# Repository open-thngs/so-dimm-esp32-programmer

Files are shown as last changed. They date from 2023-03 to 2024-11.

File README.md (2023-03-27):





---

# KiCAD-CICD-Template

This repository provides different CI/CD workflows used for projects using [KiCAD](https://www.kicad.org/) and [PlatformIO](https://platformio.org).

## workflows

### KiBot

[KiBot](https://github.com/INTI-CMNB/KiBot/) is used to generate all kind of documentation from a KiCAD6 project.

Whenever a file matching `pcb/*.kicad_*` changes this workflow will trigger.

The following documents are generated on every build:

```
- pcb/cad/
   - dxf/
      - AutoCAD - DXF
   - boardview - BRD
   - 3D render - STEP
- pcb/docs/
   - bom/
      - Interactive BOM - HTML
      - Octopart list - CSV
      - KiCost - XLSX (disabled)
   - schematic - PDF
- pcb/img/
   - pcb/$fab/$style/
      - PCB top - SVG
      - PCB bottom - SVG
   - render/ (disabled)
      - PCB render - PNG
   - schematic - SVG
- pcb/gerbers - ZIP
```

### PlatformIO

used to rebuild your source code whenever it changes.

### REUSE

used to insure every file got a propper license. 

## getting started

- [ ] hit the "use this template" button and give your project a name
- [ ] clone this new repository localy
- [ ] replace content of README.md
- [ ] Code
   - [ ] put your code in the `src/` folder using platformio
- [ ] PCB
   - [ ] change the filenames in `pcb/*.kicad_*` matching your repository name
   - [ ] create your PCB
- [ ] run `reuse --lint`
   - [ ] make sure the licenses of `pcb/*` fits your needs
   - [ ] make sure the licenses of `src/*`, `include/*`, `lib/*`, `test/*` fits your needs
- [ ] commit and push all those changes regulary to your project

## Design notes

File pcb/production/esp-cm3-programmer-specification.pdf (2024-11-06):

PCB Specifications ESP-CM3-Programmer

PCB Thickness: | 1.03mm
PCB Layer count: | 2
PCB Surface Finish: | HASL
PCB Color: | Green T/B
PCB Silkscreen: | White T/B
PCB Physical Stackup:
Layer | Type | Thickness
F.Cu | Copper | 0.035mm
Dielectric 2 | Core | 1.51mm
B.Cu | Copper | 0.035mm

Dimensions

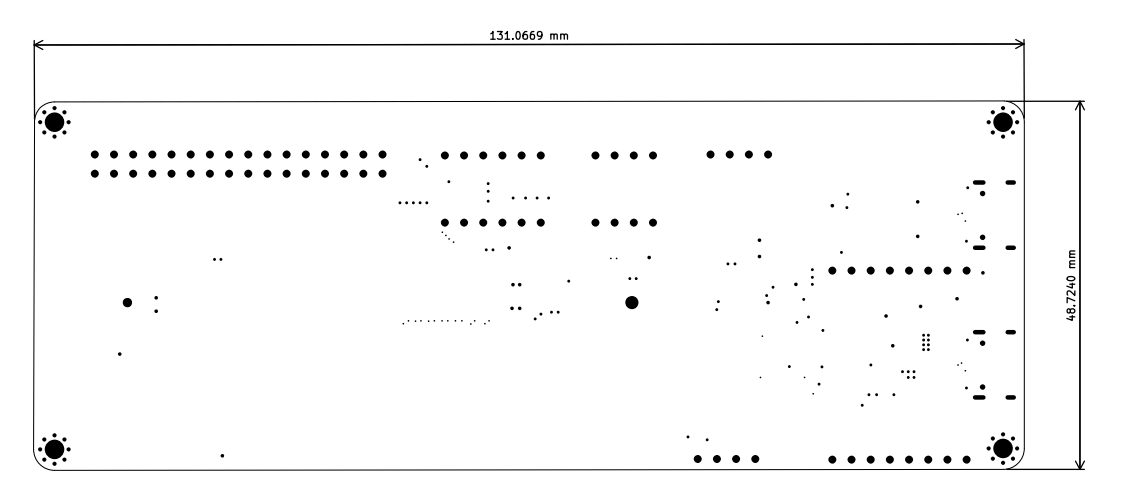
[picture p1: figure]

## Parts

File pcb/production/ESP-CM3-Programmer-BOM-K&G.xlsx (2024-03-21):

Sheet: BIL OF MATERIALS
 |  |  | Kunde: | Mirko Häberlin - open-things
 |  |  | Projektname: | Openthing 1 - ESP-CM3
 |  |  | Menge: | 20, 100
 | KRÜGER & GOTHE GMBH
 | electronic products and services
 | Atzendorfer Str. 19 • 39418 Staßfurt
 | www.kug-ems.de
Pos. | CPN interne Kundenartikelnummer costumer part number | Beschreibung Artikelparameter describtion | Referenzen credentials | T/B | Menge Quantity | MPN Herstellerteilenummer manufacturer part number | Hersteller Manufacturer | MPN Alternative 1 | Hersteller Alternative 1 | MPN Alternative 2 | Hersteller Alternative 2 | Bemerkung
0001 |  | Capacitor 1µF 0603 | C1, C2, C7, C8 | T | 4 | 1uF
0002 |  | Capacitor 0.1µF 0603 | C3, C4, C6 | T | 3 | 0.1uF
0003 |  | Capacitor 10µF 0603 | C5 | T | 1 | 10uF
0004 |  | LED Rot 0603 | D1 | T | 1 | LED RED
0005 |  | 603 | D2 | T | 1 | LED GREEN TX
0006 |  | 603 | D3 | T | 1 | LED GREEN RX
0007 |  | SCHOTTKY Diode SOD-123 | D4, D5 | T | 2 | 1N5819HW-7-F
0008 |  | DDR2-SO-DIMM-Sockel | J1 | T | 1 | 1612618-4 | TE Connectivity
0009 |  | PinHeader_1x06_P2.54mm_Vertical | J12, J2 | T | 2 | Conn_01x06_Pin
0010 |  | PinHeader_1x04_P2.54mm_Vertical | J3, J4, J9 | T | 3 | Conn_01x04_Pin
0011 |  | GCT_USB4105-GF-A | J6, J7 | T | 2 | USB4105-GF-A | Global Connector Technology (GCT) | TYPE-C-31-M-12 | Korean Hroparts Elec
0012 |  | PinHeader_2x16_P2.54mm_Vertical | J8 | T | 1 | Conn_02x16_Odd_Even
0013 |  | NPN+NPN-Digitaltransistor SOT-363_SC-70-6 | Q1 | T | 1 | UMH3N | ROHM Semiconductor
0014 |  | Widerstand 1k 0603 | R1, R10, R11, R12 | T | 4 | 1k
0015 |  | Widerstand 0R 0603 | R13, R14 | T | 2 | 0R
0016 |  | Widerstand 5.1k 0603 | R2, R4, R5, R7 | T | 4 | 5k1
0017 |  | Widerstand 10k 0603 | R3, R6 | T | 2 | 10k
0018 |  | Widerstand 22.1k 0603 | R8 | T | 1 | 22.1k
0019 |  | Widerstand 47.5k 0603 | R9 | T | 1 | 47.5k
0020 |  | Sensorschalter 3.9x2.9x2.0mm 160gf SKRKAEE020 | SW1, SW2 | T | 2 | SKRKAEE020 | Alps Alpine
0021 |  | LDO Spannungs-Regulator 600mA CMOS LDO 50mA 3.3V 250mV SOT-23-5 | U1 | T | 1 | AP2112K-3.3 | Diodes Incorporated
0022 |  | ESD-Entstörer/TVS-Dioden High Speed Interface Protection Low Cap SOT-666 | U2, U3 | T | 2 | USBLC6-2P6 | STMicroelectronics
0023 |  | USB-IC-Schnittstelle USBXpress - USB to UART Bridge QFN-28-1EP_5x5mm_P0.5mm_EP3.35x3.35mm | U4 | T | 1 | CP2102N-Axx-xQFN28 | Silicon Labs
0024
0025

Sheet: bom
Designator | Footprint | Quantity | Value | LCSC Part #
C1, C2, C7, C8 | 603 | 4 | 1uF
C3, C4, C6 | 603 | 3 | 0.1uF
C5 | 603 | 1 | 10uF
D1 | 603 | 1 | PWR_RED
D2 | 603 | 1 | LED_GREEN_TX
D3 | 603 | 1 | LED_GREEN_RX
D4, D5 | D_SOD-123 | 2 | 1N5819HW-7-F
J1 | 16126184 | 1 | 1612618-4
J12, J2 | PinHeader_1x06_P2.54mm_Vertical | 2 | Conn_01x06_Pin
J3, J4, J9 | PinHeader_1x04_P2.54mm_Vertical | 3 | Conn_01x04_Pin
J6, J7 | GCT_USB4105-GF-A | 2 | USB4105-GF-A
J8 | PinHeader_2x16_P2.54mm_Vertical | 1 | Conn_02x16_Odd_Even
Q1 | SOT-363_SC-70-6 | 1 | UMH3N
R1, R10, R11, R12 | 603 | 4 | 1k
R13, R14 | 603 | 2 | 0R
R2, R4, R5, R7 | 603 | 4 | 5k1
R3, R6 | 603 | 2 | 10k
R8 | 603 | 1 | 22.1k
R9 | 603 | 1 | 47.5k
SW1, SW2 | SKRKAEE020 | 2 | SW_Push
U1 | SOT-23-5 | 1 | AP2112K-3.3
U2, U3 | SOT-666 | 2 | USBLC6-2P6
U4 | QFN-28-1EP_5x5mm_P0.5mm_EP3.35x3.35mm | 1 | CP2102N-Axx-xQFN28

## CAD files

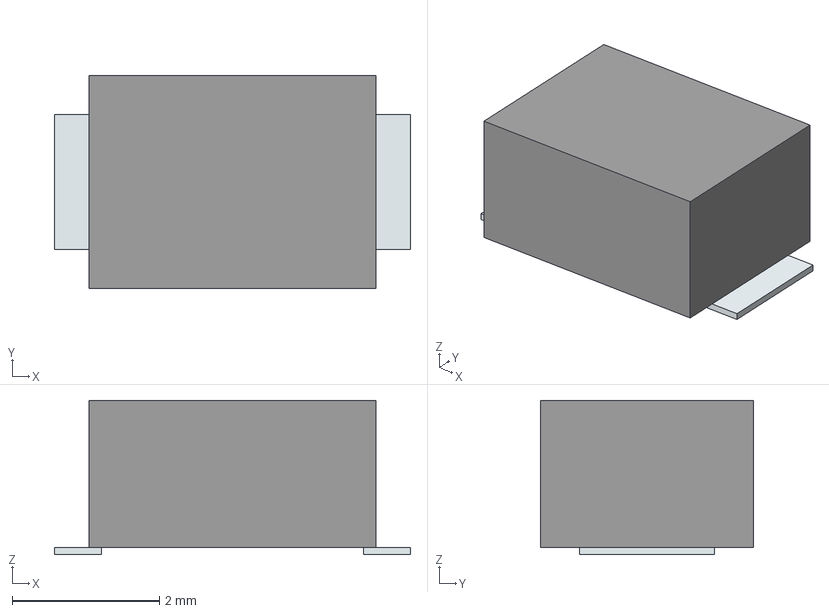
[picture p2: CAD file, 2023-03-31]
pcb/components/SKRKAEE020/SKRKAEE020.stp
4.84 x 2.90 x 2.10 mm
Pins

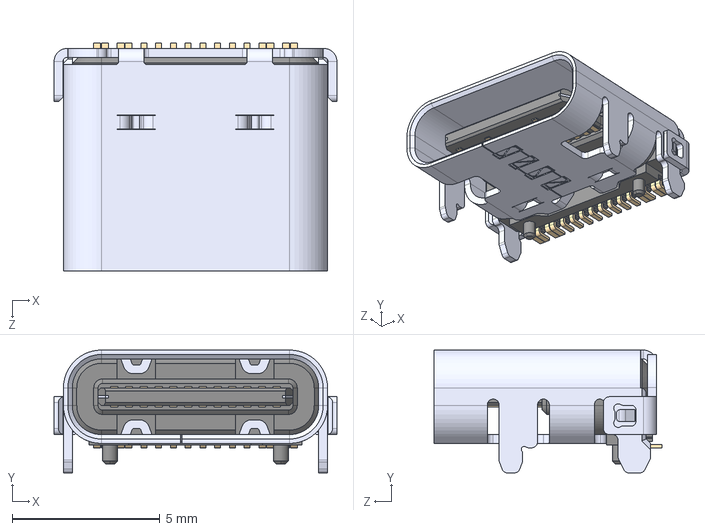
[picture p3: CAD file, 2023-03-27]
pcb/components/USB4105-GF-A/USB4105-GF-A.step
9.58 x 4.16 x 7.71 mm

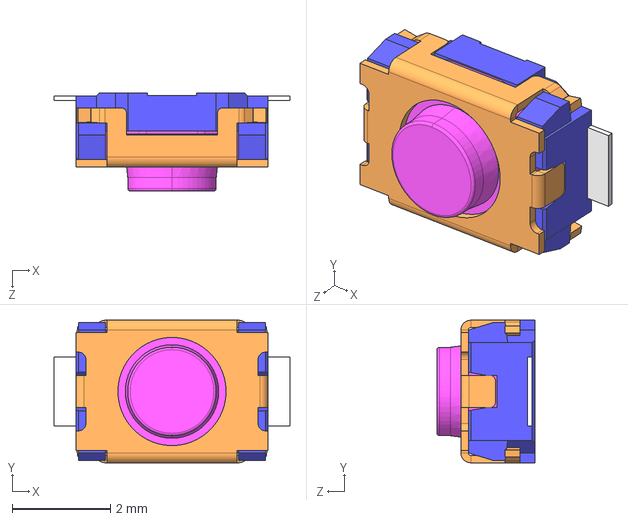
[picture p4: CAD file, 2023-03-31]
pcb/components/SKRKAEE020/SKRKAE.STEP
4.80 x 2.90 x 2.00 mm

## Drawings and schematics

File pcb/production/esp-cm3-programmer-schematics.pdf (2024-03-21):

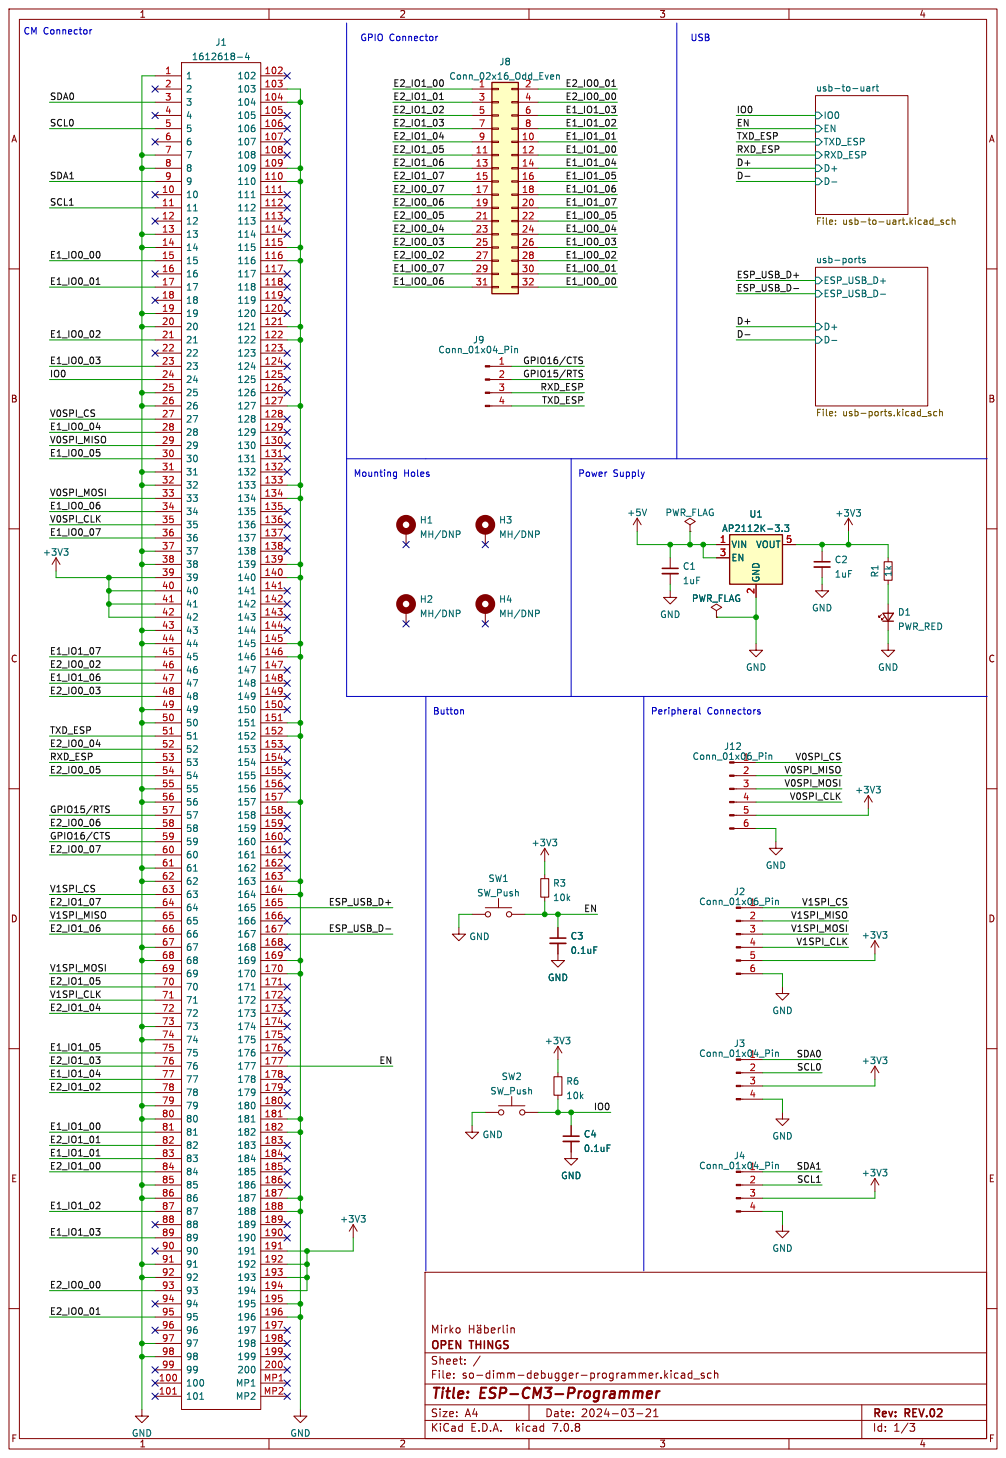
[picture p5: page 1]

usb-to-uart File: usb-to-uart.kicad_sch

ESP_USB_D+ ESP_USB_D- D+D- usb-ports File: usb-ports.kicad_sch

J2 Conn_01x06_Pin H3 MH/DNP H4 MH/DNP

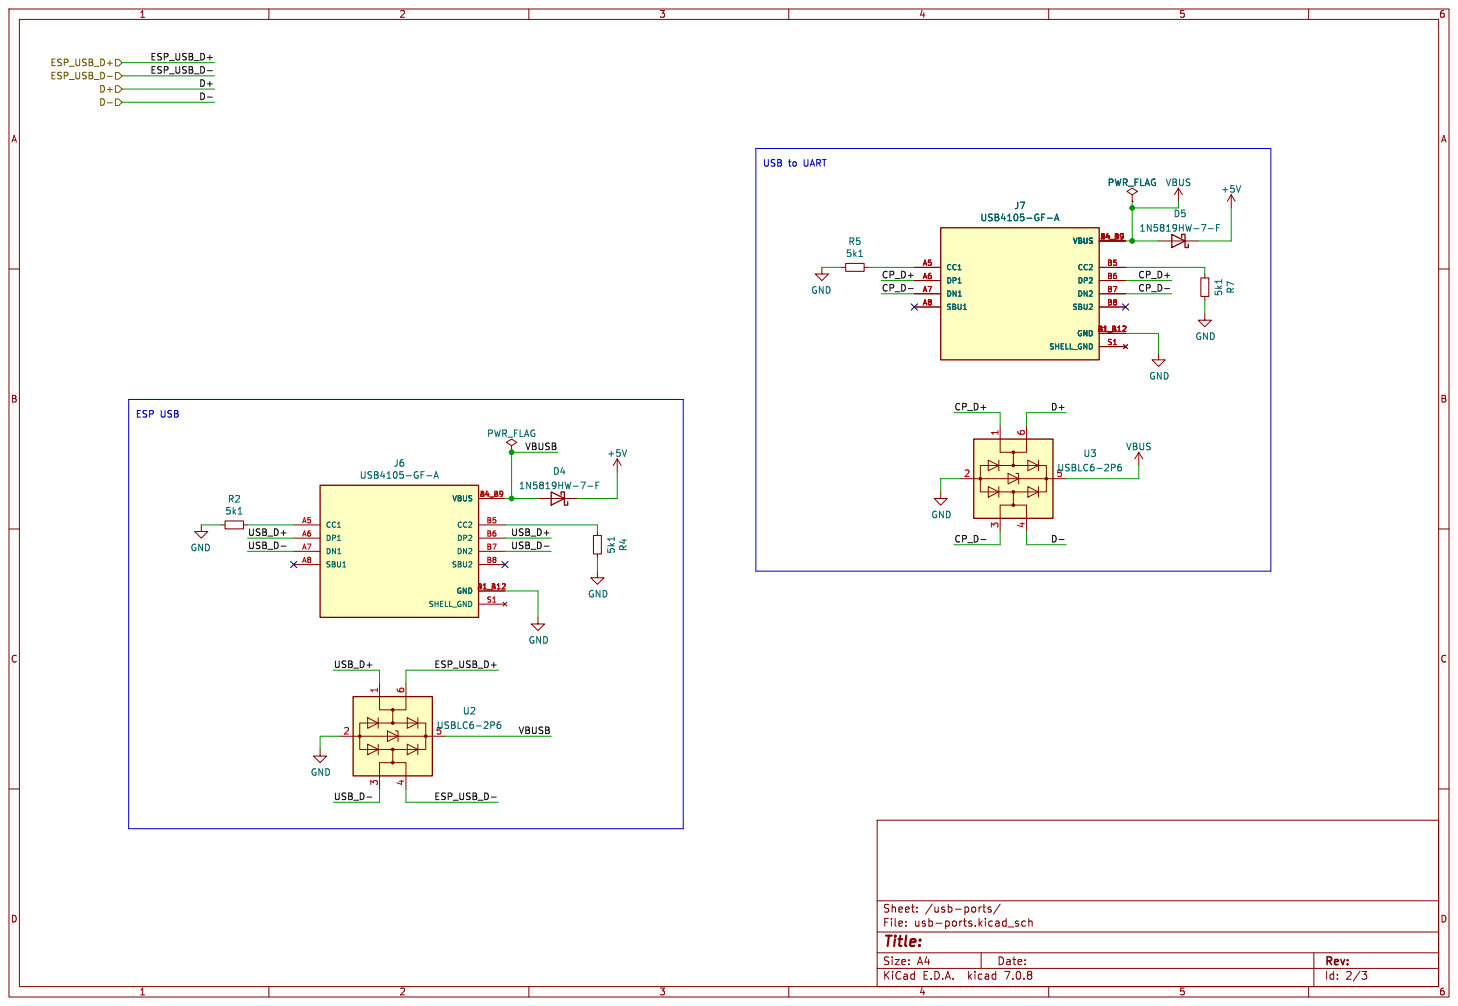
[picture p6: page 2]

Id: 2/3 Title: File: usb-ports.kicad_sch Sheet: /usb-ports/ GND

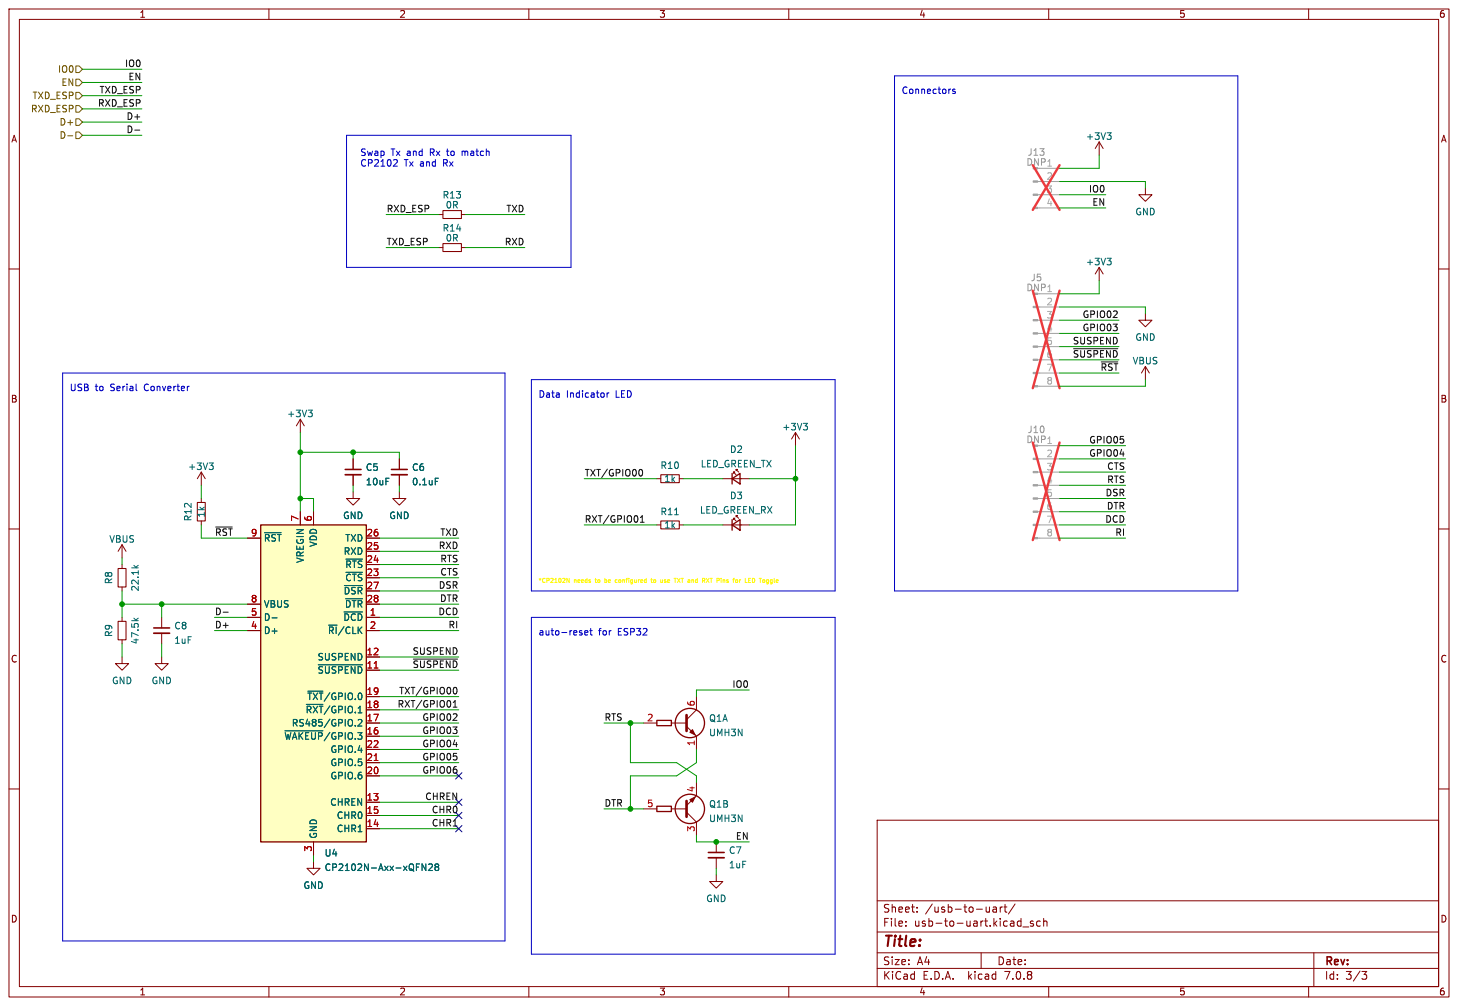
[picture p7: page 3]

Swap Tx and Rx to match CP2102 Tx and Rx

Id: 3/3 Title: File: usb-to-uart.kicad_sch Sheet: /usb-to-uart/ C5
1k GND

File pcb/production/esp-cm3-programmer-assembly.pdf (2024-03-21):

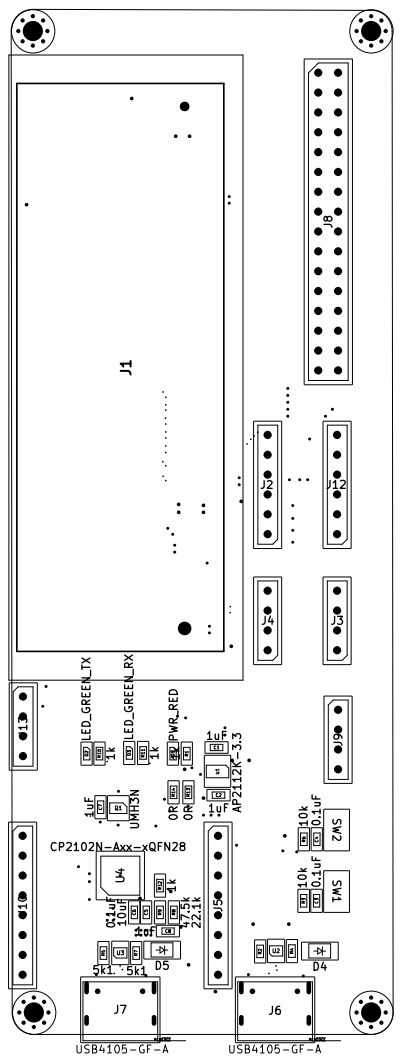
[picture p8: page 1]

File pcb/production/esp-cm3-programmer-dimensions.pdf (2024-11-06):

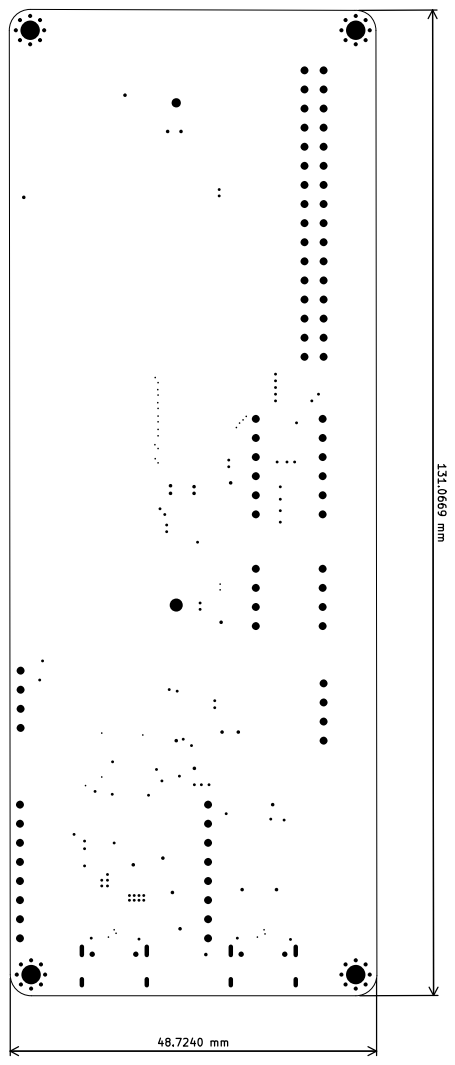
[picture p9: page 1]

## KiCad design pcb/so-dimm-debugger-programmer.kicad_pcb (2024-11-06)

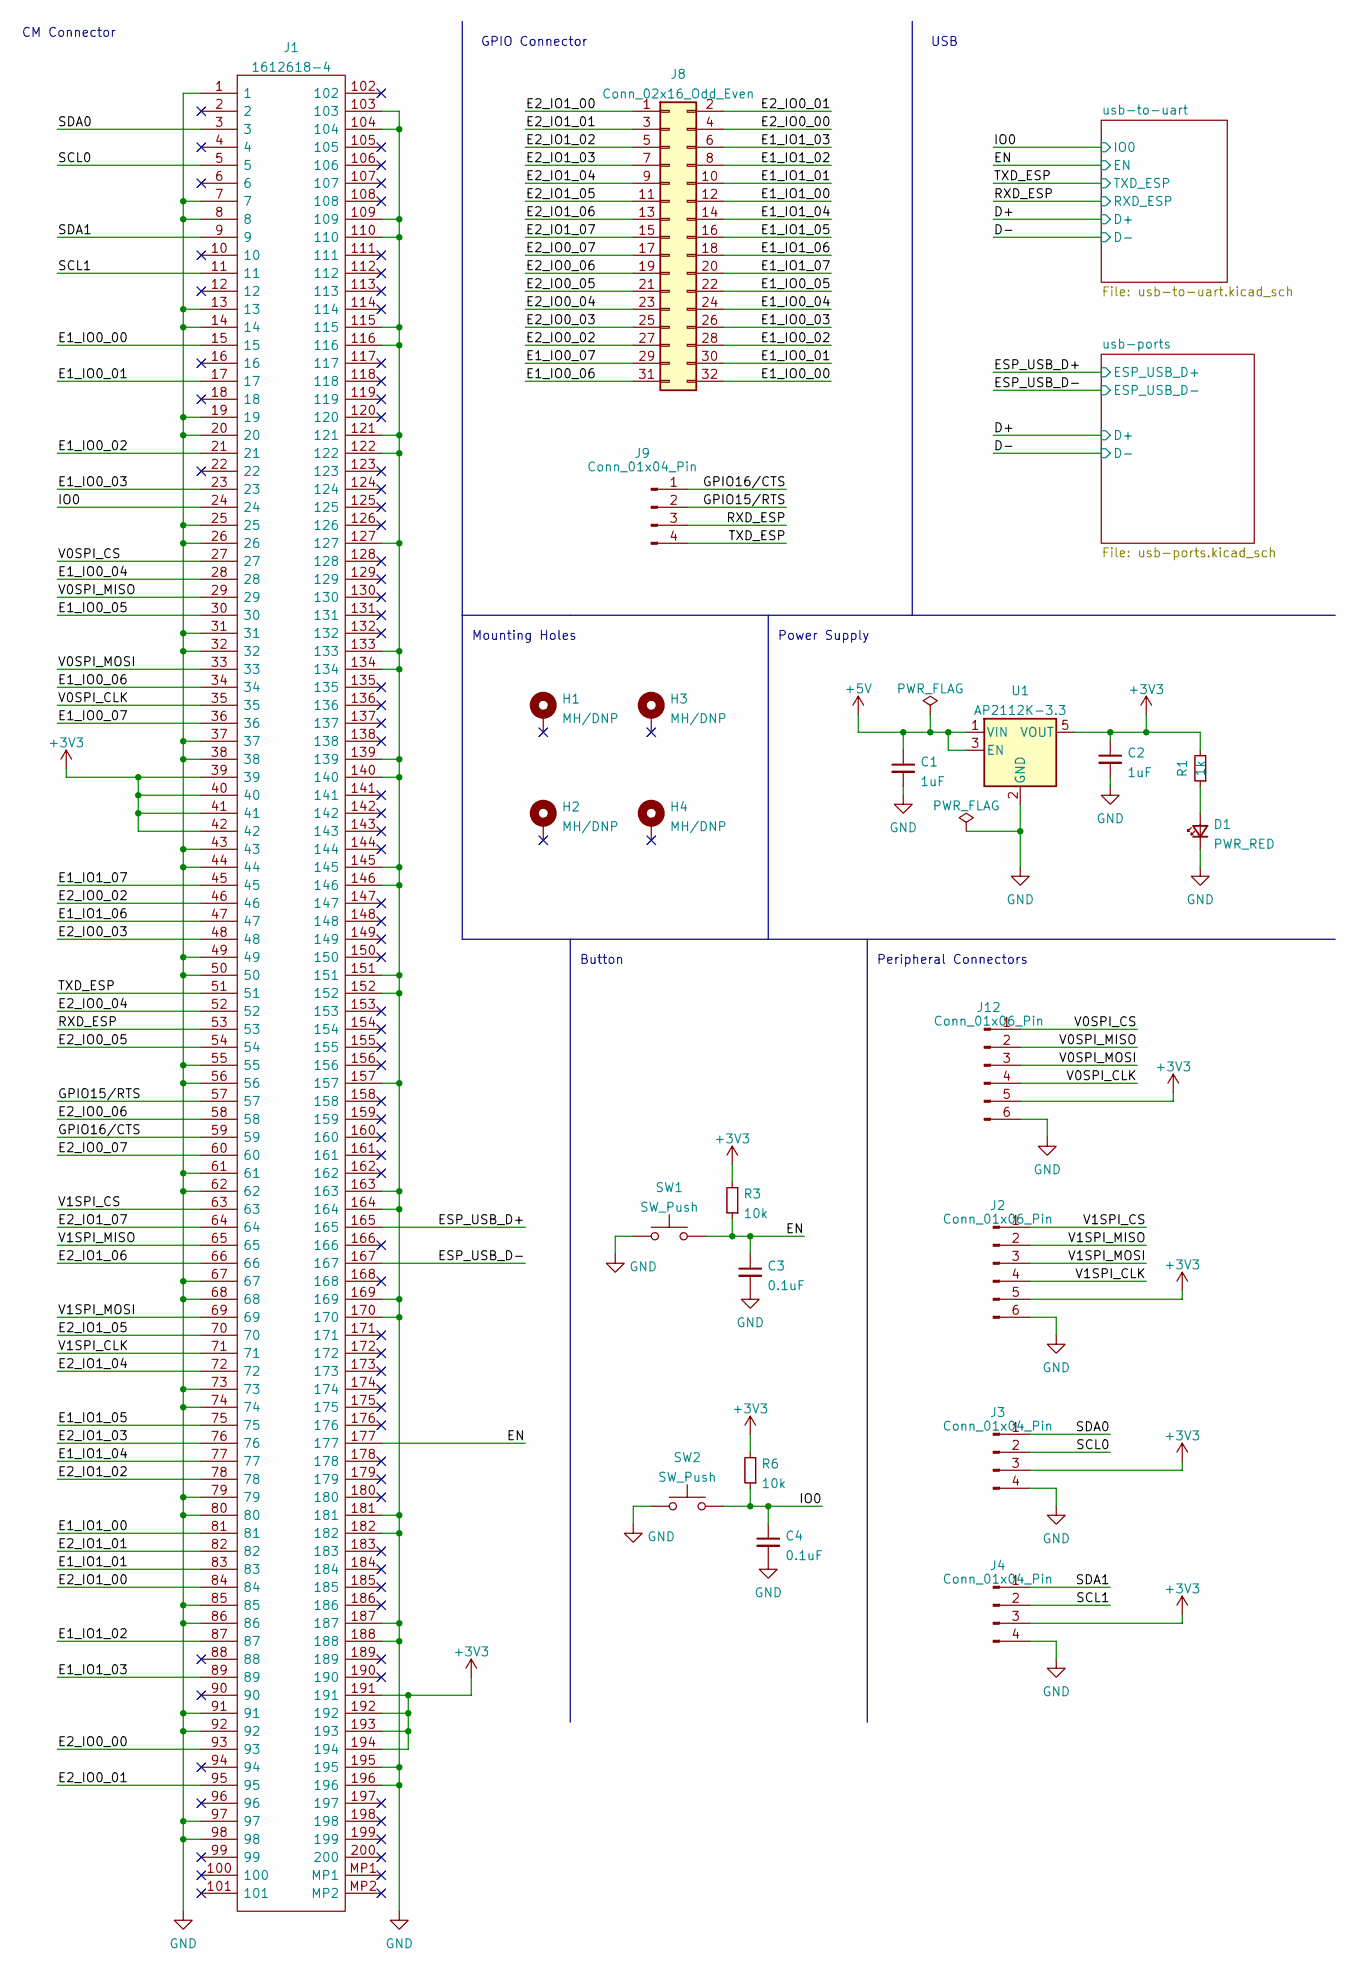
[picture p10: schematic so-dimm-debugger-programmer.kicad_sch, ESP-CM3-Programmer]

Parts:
C1, C2: 1uF; C_0603_1608Metric
C3, C4: 0.1uF; C_0603_1608Metric
D1: PWR_RED; LED_0603_1608Metric
H1, H2, H3, H4: MH/DNP; MountingHole_2.5mm_Pad_Via
J1: 1612618-4; 16126184; Manufacturer_Part_Number 1612618-4; Mouser Part Number 571-1612618-4
J2, J12: Conn_01x06_Pin; PinHeader_1x06_P2.54mm_Vertical
J3, J4, J9: Conn_01x04_Pin; PinHeader_1x04_P2.54mm_Vertical
J8: Conn_02x16_Odd_Even; PinHeader_2x16_P2.54mm_Vertical
R1: 1k; R_0603_1608Metric
R3, R6: 10k; R_0603_1608Metric
SW1, SW2: SW_Push; SKRKAEE020
U1: AP2112K-3.3; SOT-23-5

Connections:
+3V3: C2.1, J1.39, J1.40, J1.41, J1.42, J1.191, J1.192, J1.193, J1.194, J2.5, J3.3, J4.3, J12.5, R1.2, R3.2, R6.2, U1.5 (VOUT); also elsewhere on the board
+5V: C1.1, U1.1 (VIN), U1.3 (EN); also elsewhere on the board
/E1_IO0_00: J1.15, J8.32
/E1_IO0_01: J1.17, J8.30
/E1_IO0_02: J1.21, J8.28
/E1_IO0_03: J1.23, J8.26
/E1_IO0_04: J1.28, J8.24
/E1_IO0_05: J1.30, J8.22
/E1_IO0_06: J1.34, J8.31
/E1_IO0_07: J1.36, J8.29
/E1_IO1_00: J1.81, J8.12
/E1_IO1_01: J1.83, J8.10
/E1_IO1_02: J1.87, J8.8
/E1_IO1_03: J1.89, J8.6
/E1_IO1_04: J1.77, J8.14
/E1_IO1_05: J1.75, J8.16
/E1_IO1_06: J1.47, J8.18
/E1_IO1_07: J1.45, J8.20
/E2_IO0_00: J1.93, J8.4
/E2_IO0_01: J1.95, J8.2
/E2_IO0_02: J1.46, J8.27
/E2_IO0_03: J1.48, J8.25
/E2_IO0_04: J1.52, J8.23
/E2_IO0_05: J1.54, J8.21
/E2_IO0_06: J1.58, J8.19
/E2_IO0_07: J1.60, J8.17
/E2_IO1_00: J1.84, J8.1
/E2_IO1_01: J1.82, J8.3
/E2_IO1_02: J1.78, J8.5
/E2_IO1_03: J1.76, J8.7
/E2_IO1_04: J1.72, J8.9
/E2_IO1_05: J1.70, J8.11
/E2_IO1_06: J1.66, J8.13
/E2_IO1_07: J1.64, J8.15
/EN: C3.1, J1.177, R3.1, SW1.2; also elsewhere on the board
/ESP_USB_D+: J1.165; also elsewhere on the board
/ESP_USB_D-: J1.167; also elsewhere on the board
/GPIO15/RTS: J1.57, J9.2
/GPIO16/CTS: J1.59, J9.1
/IO0: C4.1, J1.24, R6.1, SW2.2; also elsewhere on the board
/RXD_ESP: J1.53, J9.3; also elsewhere on the board
/SCL0: J1.5, J3.2
/SCL1: J1.11, J4.2
/SDA0: J1.3, J3.1
/SDA1: J1.9, J4.1
/TXD_ESP: J1.51, J9.4; also elsewhere on the board
/V0SPI_CLK: J1.35, J12.4
/V0SPI_CS: J1.27, J12.1
/V0SPI_MISO: J1.29, J12.2
/V0SPI_MOSI: J1.33, J12.3
/V1SPI_CLK: J1.71, J2.4
/V1SPI_CS: J1.63, J2.1
/V1SPI_MISO: J1.65, J2.2
/V1SPI_MOSI: J1.69, J2.3
GND: C1.2, C2.2, C3.2, C4.2, D1.1 (K), J1.1, J1.7, J1.8, J1.13, J1.14, J1.19, J1.20, J1.25, J1.26, J1.31, J1.32, J1.37, J1.38, J1.43, J1.44, J1.49, J1.50, J1.55, J1.56, J1.61, J1.62, J1.67, J1.68, J1.73, J1.74, J1.79, J1.80, J1.85, J1.86, J1.91, J1.92, J1.97, J1.98, J1.103, J1.104, J1.109, J1.110, J1.115, J1.116, J1.121, J1.122, J1.127, J1.133, J1.134, J1.139, J1.140, J1.145, J1.146, J1.151, J1.152, J1.157, J1.163, J1.164, J1.169, J1.170, J1.181, J1.182, J1.187, J1.188, J1.195, J1.196, J2.6, J3.4, J4.4, J12.6, SW1.1, SW2.1, U1.2 (GND); also elsewhere on the board
unnamed: D1.2 (A), R1.1

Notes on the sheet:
Mounting Holes
CM Connector
USB
GPIO Connector
Peripheral Connectors
Button
Power Supply

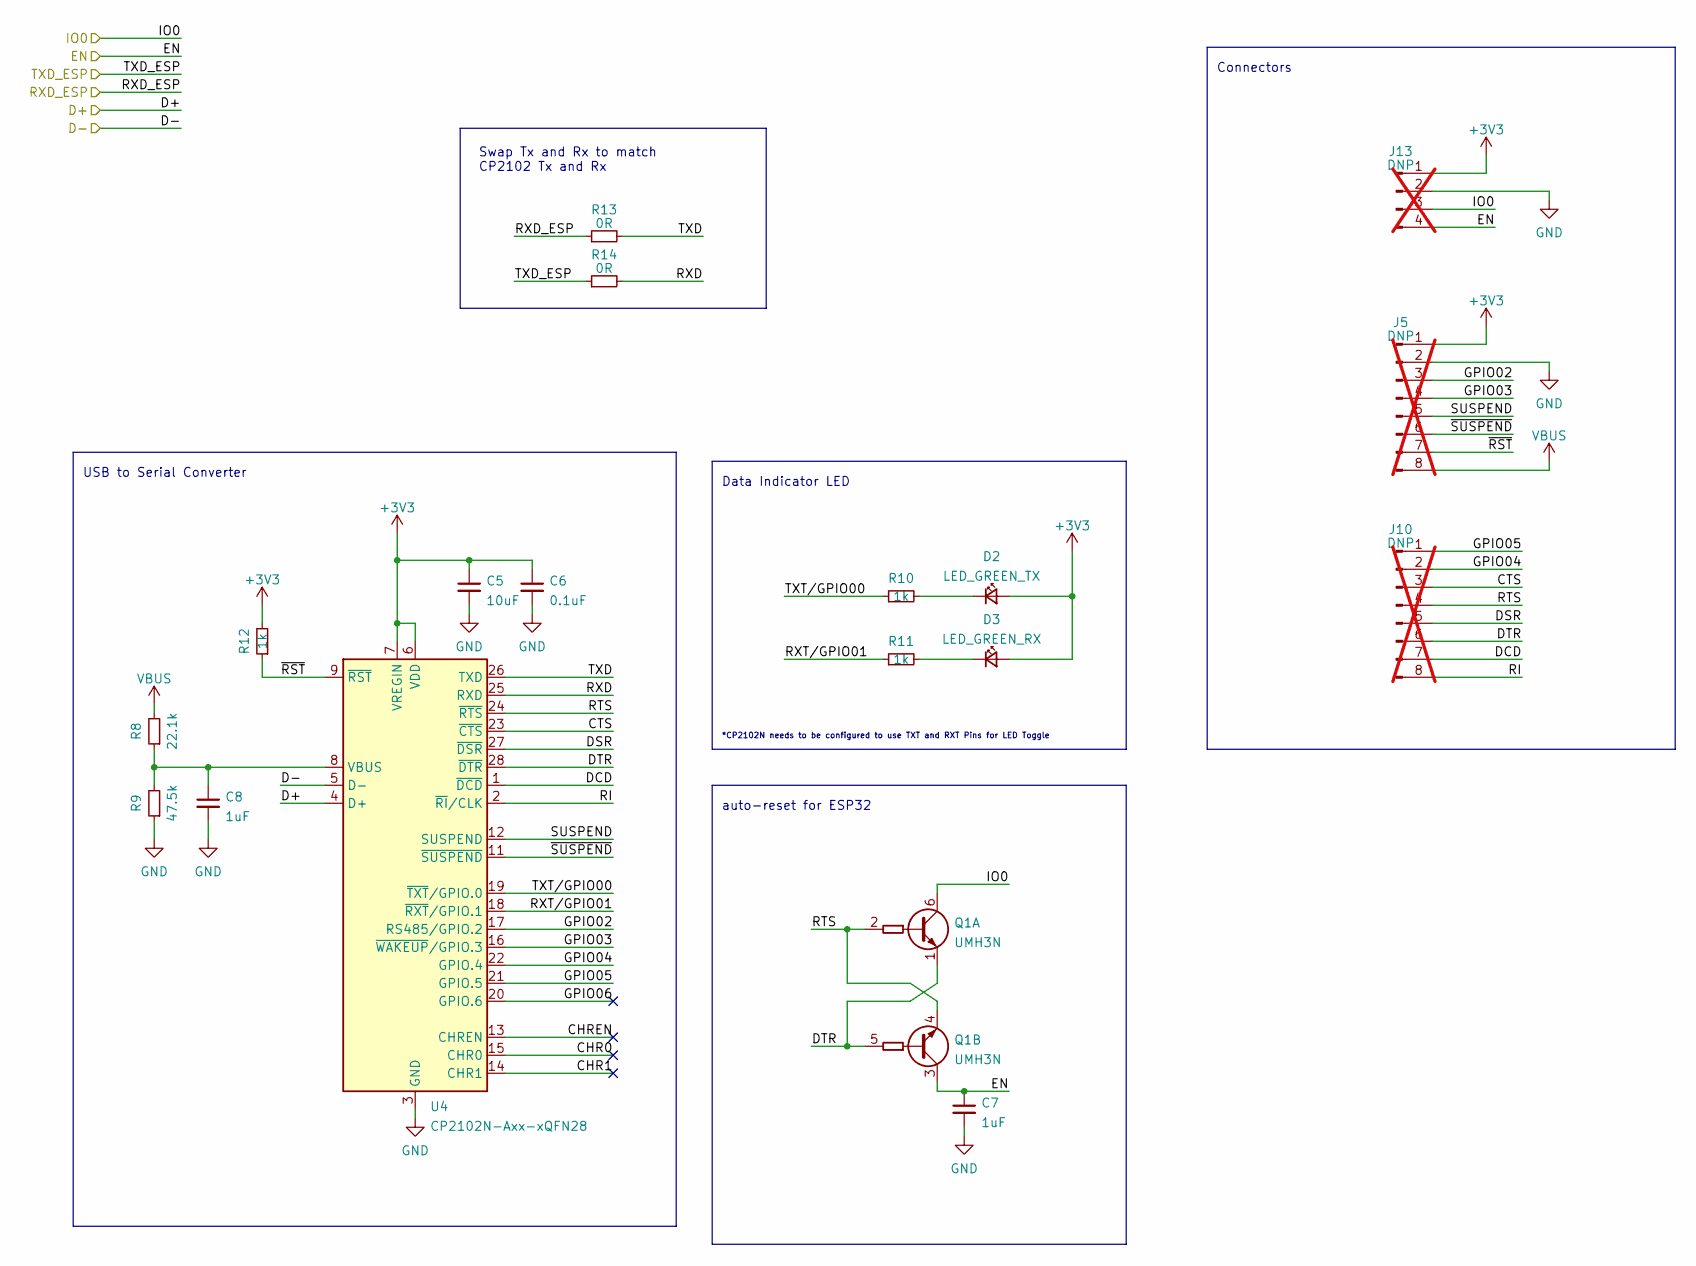
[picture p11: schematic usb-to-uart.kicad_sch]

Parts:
C5: 10uF; C_0603_1608Metric
C6: 0.1uF; C_0603_1608Metric
C7, C8: 1uF; C_0603_1608Metric
D2: LED_GREEN_TX; LED_0603_1608Metric
D3: LED_GREEN_RX; LED_0603_1608Metric
J5, J10: DNP; PinHeader_1x08_P2.54mm_Vertical; not fitted
J13: DNP; PinHeader_1x04_P2.54mm_Vertical; not fitted
Q1: UMH3N; SOT-363_SC-70-6
R8: 22.1k; R_0603_1608Metric
R9: 47.5k; R_0603_1608Metric
R10, R11, R12: 1k; R_0603_1608Metric
R13, R14: 0R; R_0603_1608Metric
U4: CP2102N-Axx-xQFN28; QFN-28-1EP_5x5mm_P0.5mm_EP3.35x3.35mm

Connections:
+3V3: C5.1, C6.1, D2.2 (A), D3.2 (A), J5.1, J13.1, R12.2, U4.6 (VDD), U4.7 (VREGIN); also elsewhere on the board
/D+: U4.4 (D+); also elsewhere on the board
/D-: U4.5 (D-); also elsewhere on the board
/EN: C7.1, J13.4, Q1.3 (C2); also elsewhere on the board
/IO0: J13.3, Q1.6 (C1); also elsewhere on the board
/RXD_ESP: R13.1; also elsewhere on the board
/TXD_ESP: R14.1; also elsewhere on the board
/usb-to-uart/CHR0: U4.15 (CHR0)
/usb-to-uart/CHR1: U4.14 (CHR1)
/usb-to-uart/CHREN: U4.13 (CHREN)
/usb-to-uart/CTS: J10.3, U4.23 (~CTS)
/usb-to-uart/DCD: J10.7, U4.1 (~DCD)
/usb-to-uart/DSR: J10.5, U4.27 (~DSR)
/usb-to-uart/DTR: J10.6, Q1.1 (E1), Q1.5 (B2), U4.28 (~DTR)
/usb-to-uart/GPIO02: J5.3, U4.17 (RS485/GPIO.2)
/usb-to-uart/GPIO03: J5.4, U4.16 (~WAKEUP/GPIO.3)
/usb-to-uart/GPIO04: J10.2, U4.22 (GPIO.4)
/usb-to-uart/GPIO05: J10.1, U4.21 (GPIO.5)
/usb-to-uart/GPIO06: U4.20 (GPIO.6)
/usb-to-uart/RI: J10.8, U4.2 (~RI/CLK)
/usb-to-uart/RTS: J10.4, Q1.2 (B1), Q1.4 (E2), U4.24 (~RTS)
/usb-to-uart/RXD: R14.2, U4.25 (RXD)
/usb-to-uart/RXT/GPIO01: R11.1, U4.18 (~RXT/GPIO.1)
/usb-to-uart/SUSPEND: J5.5, U4.12 (SUSPEND)
/usb-to-uart/TXD: R13.2, U4.26 (TXD)
/usb-to-uart/TXT/GPIO00: R10.1, U4.19 (~TXT/GPIO.0)
/usb-to-uart/~RST: J5.7, R12.1, U4.9 (~RST)
/usb-to-uart/~SUSPEND: J5.6, U4.11 (~SUSPEND)
GND: C5.2, C6.2, C7.2, C8.2, J5.2, J13.2, R9.1, U4.3 (GND), U4.29 (GND); also elsewhere on the board
unnamed: D2.1 (K), R10.2
unnamed: D3.1 (K), R11.2
unnamed: C8.1, R8.1, R9.2, U4.8 (VBUS)
VBUS: J5.8, R8.2; also elsewhere on the board

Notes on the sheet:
Swap Tx and Rx to match CP2102 Tx and Rx
Connectors
USB to Serial Converter
*CP2102N needs to be configured to use TXT and RXT Pins for LED Toggle
Data Indicator LED
auto-reset for ESP32

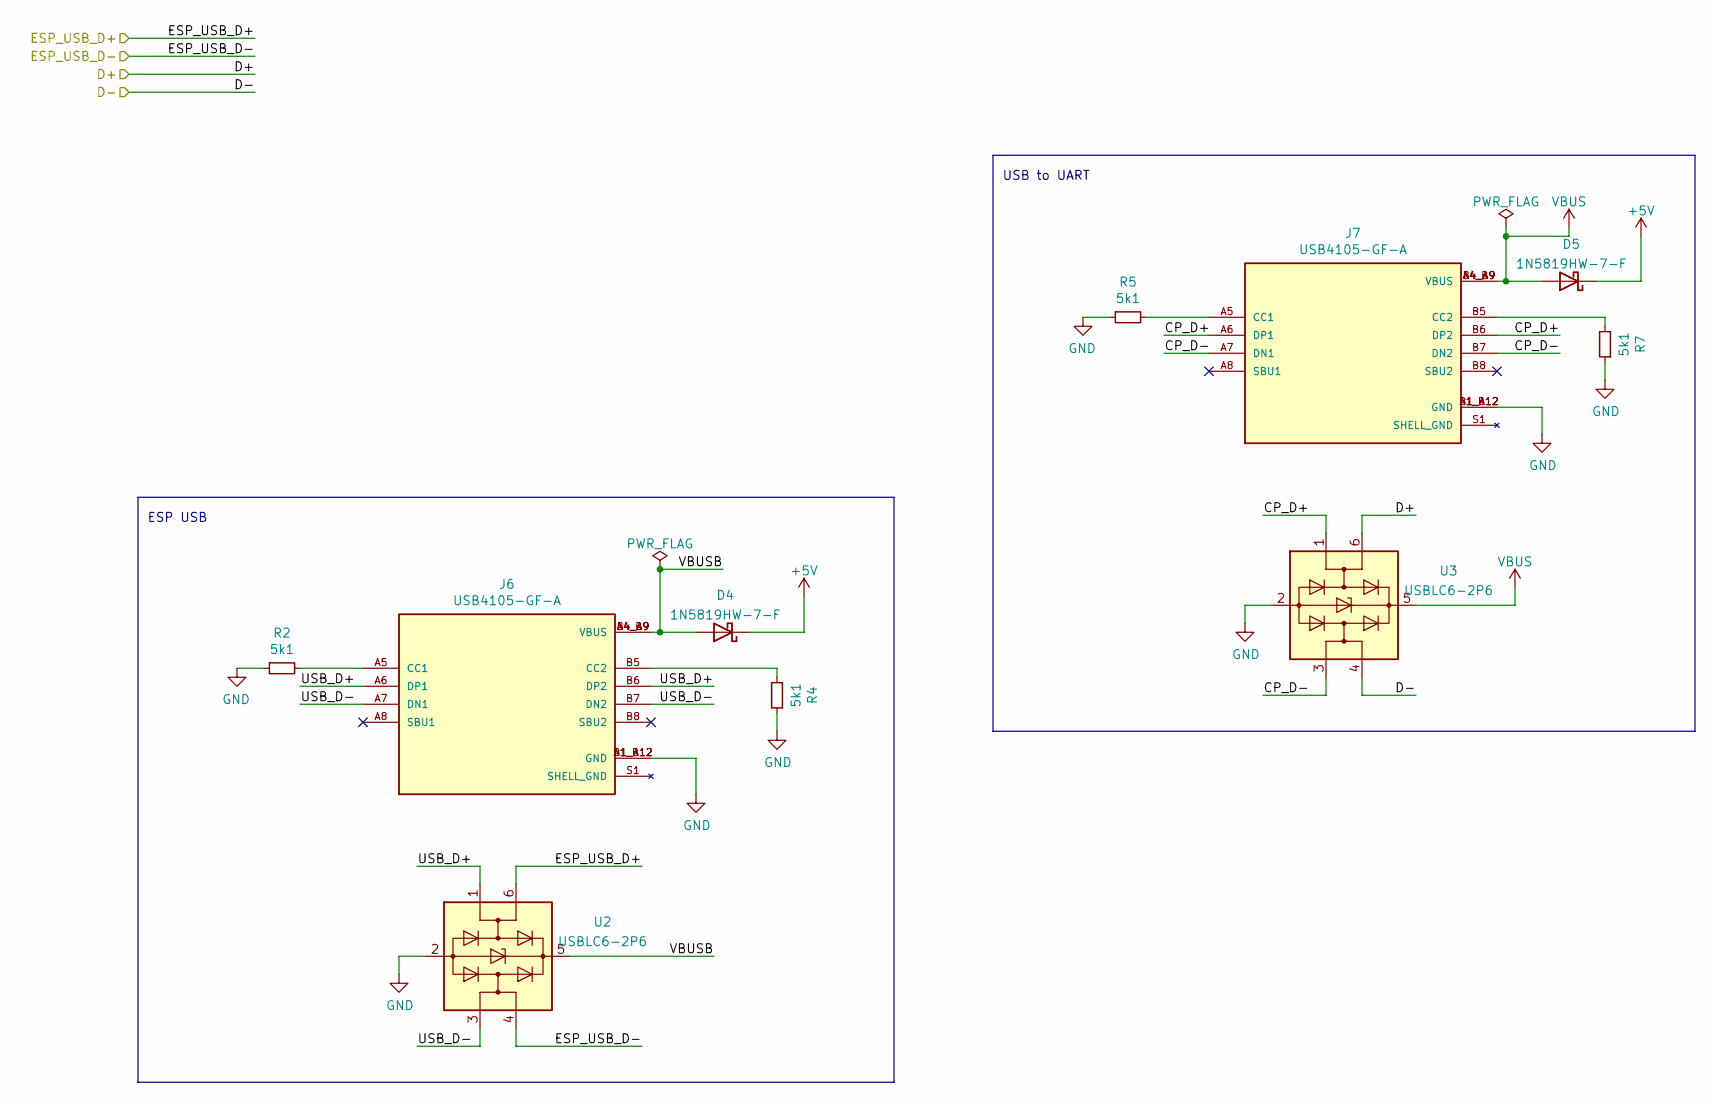
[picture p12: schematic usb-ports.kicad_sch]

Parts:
D4, D5: 1N5819HW-7-F; D_SOD-123
J6, J7: USB4105-GF-A; GCT_USB4105-GF-A; PARTREV A3
R2, R4, R5, R7: 5k1; R_0603_1608Metric
U2, U3: USBLC6-2P6; SOT-666

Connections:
+5V: D4.1 (K), D5.1 (K); also elsewhere on the board
/D+: U3.6 (I/O1); also elsewhere on the board
/D-: U3.4 (I/O2); also elsewhere on the board
/ESP_USB_D+: U2.6 (I/O1); also elsewhere on the board
/ESP_USB_D-: U2.4 (I/O2); also elsewhere on the board
/usb-ports/CP_D+: J7.A6 (DP1), J7.B6 (DP2), U3.1 (I/O1)
/usb-ports/CP_D-: J7.A7 (DN1), J7.B7 (DN2), U3.3 (I/O2)
/usb-ports/USB_D+: J6.A6 (DP1), J6.B6 (DP2), U2.1 (I/O1)
/usb-ports/USB_D-: J6.A7 (DN1), J6.B7 (DN2), U2.3 (I/O2)
/usb-ports/VBUSB: D4.2 (A), J6.A4_B9 (VBUS), J6.B4_A9 (VBUS), U2.5 (VBUS)
GND: J6.A1_B12 (GND), J6.B1_A12 (GND), J7.A1_B12 (GND), J7.B1_A12 (GND), R2.1, R4.1, R5.1, R7.1, U2.2 (GND), U3.2 (GND); also elsewhere on the board
unnamed: J6.A5 (CC1), R2.2
unnamed: J6.B5 (CC2), R4.2
unnamed: J7.A5 (CC1), R5.2
unnamed: J7.B5 (CC2), R7.2
VBUS: D5.2 (A), J7.A4_B9 (VBUS), J7.B4_A9 (VBUS), U3.5 (VBUS); also elsewhere on the board

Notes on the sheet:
ESP USB
USB to UART

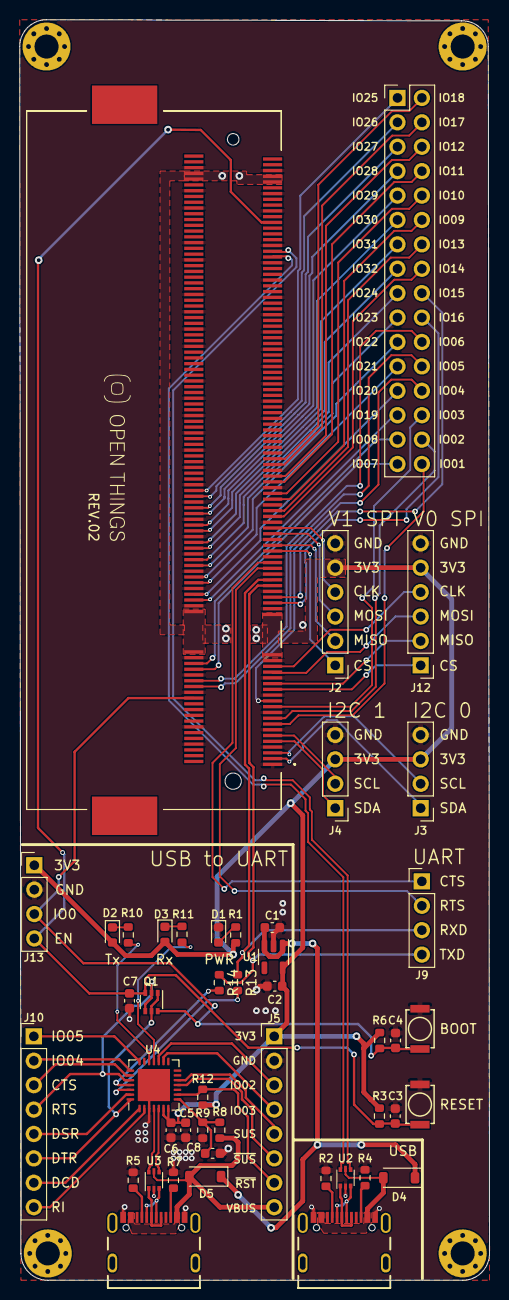
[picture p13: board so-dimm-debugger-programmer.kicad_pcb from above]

Board: 2 copper layers, 48.9 x 131.2 mm, 51 parts (0 on the bottom side), 88 nets.

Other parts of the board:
G1: LOGO

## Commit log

2023-03-27 Add inital esp32 programmer pcb data
    [KiBot-CICD-Template.kicad_pcb, KiBot-CICD-Template.kicad_sch, USB4105-GF-A.step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]
2023-03-31 Added first version of the pcb layout
    [SKRKAE.STEP, SKRKAEE020.stp, so-dimm-debugger-programmer.kicad_pcb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]
2023-03-31 Finished up board layout
    [so-dimm-debugger-programmer.kicad_pcb]
2023-03-31 Try to fix all ERC and DRC Issues and Warning + changed violation config
    [so-dimm-debugger-programmer.kicad_pcb, so-dimm-debugger-programmer.kicad_sch, usb-to-uart.kicad_sch]
2023-04-03 Small PCB silk adjustments
    [so-dimm-debugger-programmer.kicad_pcb]
2023-04-05 Removed download and install of font from kicad action for kibot
2023-06-23 Fixed Rx Tx not being swapped between CP2102 and ESP-CM3 connector
    + Fix Label for PWR and Rx (swapped)
    [so-dimm-debugger-programmer.kicad_pcb, so-dimm-debugger-programmer.kicad_sch, usb-to-uart.kicad_sch]
2023-09-08 Modified 3D objects
    [so-dimm-debugger-programmer.kicad_pcb]
2023-09-08 Ignore SPICE issues
    [usb-to-uart.kicad_sch]
2023-09-12 Fix E1_IO0_3 connected to Pin 22 instead of 23
    [so-dimm-debugger-programmer.kicad_pcb, so-dimm-debugger-programmer.kicad_sch]
2023-09-13 Fix font issue with KiCad returning to default font
    [so-dimm-debugger-programmer.kicad_pcb]
2023-09-13 Fix unconnected plane
    [so-dimm-debugger-programmer.kicad_pcb]
2023-09-29 Removed unpopulated pin header from BOM
    [so-dimm-debugger-programmer.kicad_sch, usb-to-uart.kicad_sch]
2023-09-29 Added revision silk to top layer
    [so-dimm-debugger-programmer.kicad_pcb]
2023-09-29 Added date and revision to schematic
    [so-dimm-debugger-programmer.kicad_sch]
2023-10-09 Fix copper to edge issue
    [so-dimm-debugger-programmer.kicad_pcb]
2023-10-09 Change copper to edge clearance from 0.025 to 0.25
    [so-dimm-debugger-programmer.kicad_pcb]
2023-10-20 Enabled designators for terminal connectors
    [so-dimm-debugger-programmer.kicad_pcb]
2023-10-20 Change silk-text size for terminal connectors from 0.6 to 0.8
    [so-dimm-debugger-programmer.kicad_pcb]
2023-10-20 Fixed thermal reliefe count for serveral pads
    [so-dimm-debugger-programmer.kicad_pcb]
2024-03-15 Changed excludes from BOM
    [so-dimm-debugger-programmer.kicad_pcb, usb-to-uart.kicad_sch]
2024-03-21 Added generated data
    [ESP-CM3-Programmer-BOM-K&G.xlsx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]
2024-03-21 Set USB Ports to be TH instead of SMD
    [so-dimm-debugger-programmer.kicad_pcb]
2024-11-06 Add production files specification and board dimensions
2024-11-06 small pcb changes?
    [so-dimm-debugger-programmer.kicad_pcb]
